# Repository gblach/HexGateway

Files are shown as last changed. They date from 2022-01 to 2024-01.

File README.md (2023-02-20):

# HexGateway
An internet gateway for Bluetooth LE, OpenThread and/or Zigbee devices.

It employs three chips:
- nrf52840 - has support for Bluetooth LE, OpenThread and Zigbee networks.
- esp32-c3 - has support for WiFi at 2.4GHz.
- enc28j60 - has support for Ethernet network.

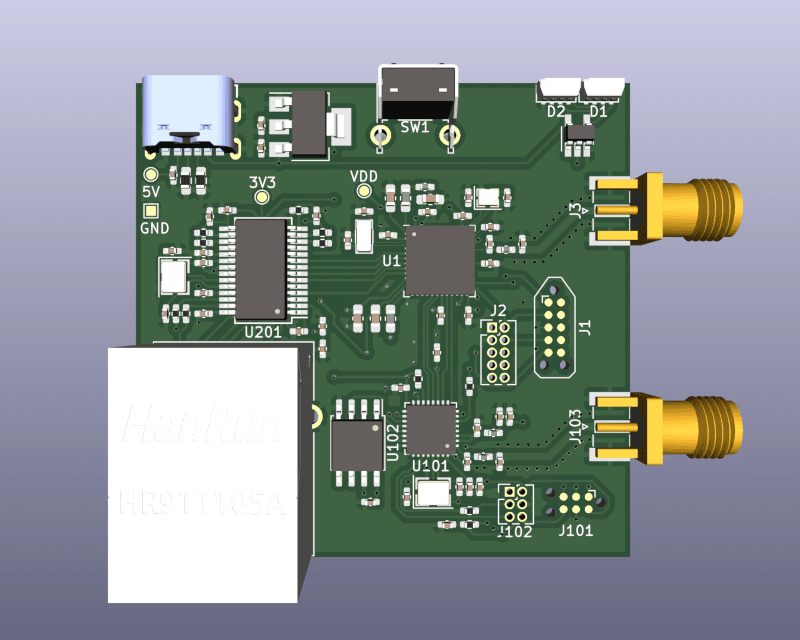
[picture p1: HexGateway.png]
HexGateway render


## Hardware
To build your own board you need this [gerber file](HexGateway.zip) and [bill of materials](HexGateway.csv).

Note that U102 is required only if your are using esp32-c3 (U101) without built-in flash memory.

## Programmers
nrf52840 (U1) can be programmed using the standalone [Segger J-Link](https://www.segger.com/products/debug-probes/j-link/) or the on-board Segger J-Link (this can be found for e.g. on [nrf52840dk](https://www.nordicsemi.com/Products/Development-hardware/nRF52840-DK) board). This programmer must be connected to J1 (TagConnect) or J2 (IDC 10) connector.

esp32-c3 (U101) can be programmed using [ESP-Prog](https://docs.espressif.com/projects/espressif-esp-iot-solution/en/latest/hw-reference/ESP-Prog_guide.html). This programmer must be connected to J101 (TagConnect) or J102 (IDC 6) connector.

enc28j60 (U201) does not need to be programmed.

## Software
For the nrf52840 chip you have to write your own software that will meet your requirements. The best way is to use [Zephyr RTOS](https://www.zephyrproject.org/). The board definition for Zephyr can be found in [boards/arm/hexgw1](boards/arm/hexgw1) directory.

esp32-c3 can be controlled with AT commands. To do this, you need to upload [ESP-AT](https://github.com/espressif/esp-at) firmware.

## Sponsorship
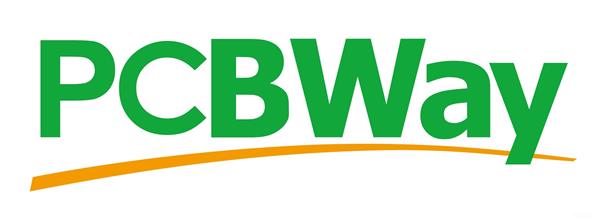
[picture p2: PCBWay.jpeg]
PCBWay (https://pcbway.com/g/7D2Z6d)


The production of these gateways was sponsored by [PCBWay](https://pcbway.com/g/7D2Z6d), they manufacture prototype PCBs and assemble components on the boards. I got 5 almost complete devices from this company for testing and evaluation, I had to solder only connectors for antennas and RJ45 ports by myself.

The visual impression of the boards is very good. All the contacts are gold plated, the silkscreen is readable, the whole board is thoroughly covered with soldiermask and all the components are soldered with a small amount of tin, so I was not worried about a potential short circuit anywhere.

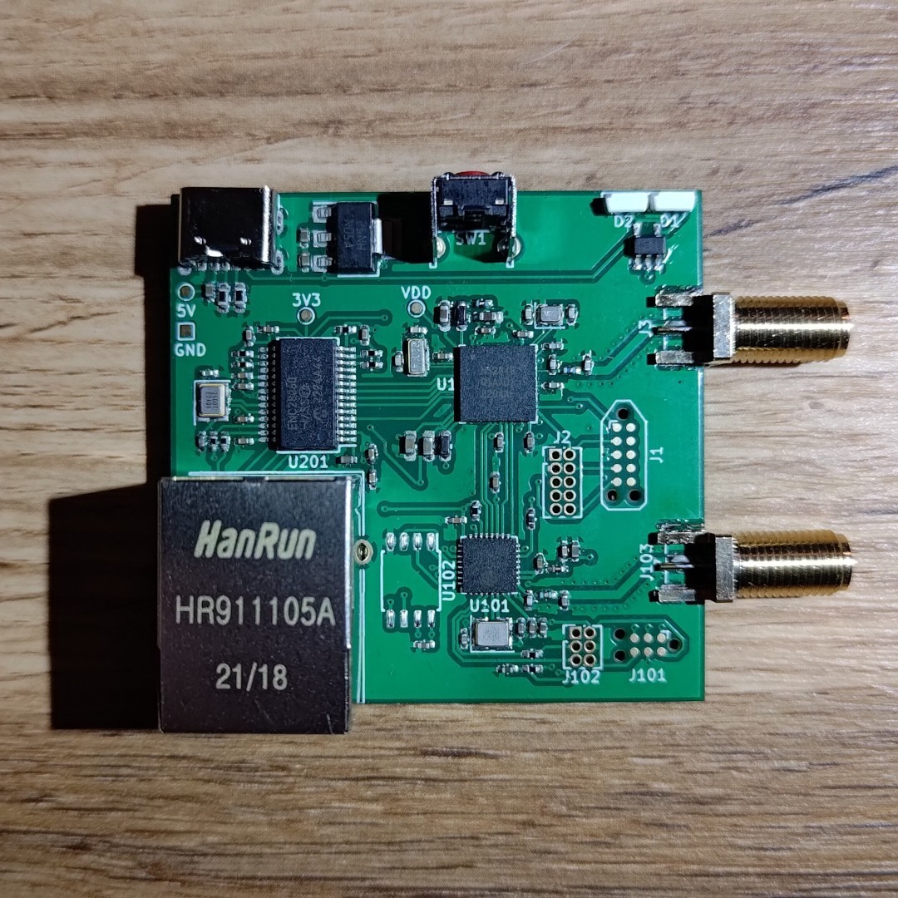
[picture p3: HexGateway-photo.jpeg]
HexGateway photo


So it remained to upload test programs to check if everything works properly. First I uploaded ESP-AT to the ESP32-C3 chips, and that passed without any problem. Next, I uploaded four programs one at a time to the nRF52840 chips. The first to check if bluetooth works, the second to check WiFi operation, the third to check Ethernet and the fourth to check LEDs. In the case of 4/5 boards, everything works as expected, so they are fully functional devices. However, for the fifth one, the programmer gave me a message that it does not detect the voltage of the processor. With a multimeter I checked the voltage on the VDD pin and there was indeed 0V there. This means that this chip is defective or more likely not all pins are soldered correctly. I am not surprised by this situation, because the nrf52840 chip has very small and densely spaced pins, so if something was to be soldered wrong, it would be with this chip.

My final rating for the quality of devices produced by [PCBWay](https://pcbway.com/g/7D2Z6d) is 4/5 stars, and this is higher than the two competing companies I have worked with. So I will probably change the company where I will produce the PCBs in the future.

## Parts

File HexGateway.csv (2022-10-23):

Ref | Qnty | Value | Cmp name | Footprint | Description | Vendor
C1, C2, C17, C18, | 4 | 12pF, NP0, 2% | C | Capacitor_SMD:C_0402_1005Metric_Pad0.74x0.62mm_HandSolder | Unpolarized capacitor
C3, | 1 | 0.8pF, NP0, 10% | C | Capacitor_SMD:C_0402_1005Metric_Pad0.74x0.62mm_HandSolder | Unpolarized capacitor
C4, | 1 | 0.5pF, NP0, 10% | C | Capacitor_SMD:C_0402_1005Metric_Pad0.74x0.62mm_HandSolder | Unpolarized capacitor
C5, C7, C8, C12, C106, C107, C110, C112, C201, C202, C203, C204, C205, C208, C209, | 15 | 100nF, X7R, 10% | C | Capacitor_SMD:C_0402_1005Metric_Pad0.74x0.62mm_HandSolder | Unpolarized capacitor
C6, C19, | 2 | 4.7uF, X7R, 10% | C | Capacitor_SMD:C_0603_1608Metric_Pad1.08x0.95mm_HandSolder | Unpolarized capacitor
C9, | 1 | 820pF, NP0, 5% | C | Capacitor_SMD:C_0402_1005Metric_Pad0.74x0.62mm_HandSolder | Unpolarized capacitor
C11, | 1 | 100pF, NP0, 5% | C | Capacitor_SMD:C_0402_1005Metric_Pad0.74x0.62mm_HandSolder | Unpolarized capacitor
C14, C15, | 2 | 1.0uF, X7R, 10% | C | Capacitor_SMD:C_0603_1608Metric_Pad1.08x0.95mm_HandSolder | Unpolarized capacitor
C16, | 1 | 47nF, X7R, 10% | C | Capacitor_SMD:C_0402_1005Metric_Pad0.74x0.62mm_HandSolder | Unpolarized capacitor
C50, C51, C52, C105, C211, | 5 | 10uF, 20% | C | Capacitor_SMD:C_0402_1005Metric_Pad0.74x0.62mm_HandSolder | Unpolarized capacitor
C101, C102, C220, C221, | 4 | 20pF | C | Capacitor_SMD:C_0402_1005Metric_Pad0.74x0.62mm_HandSolder | Unpolarized capacitor
C103, C111, C150, | 3 | 1uF, 20% | C | Capacitor_SMD:C_0402_1005Metric_Pad0.74x0.62mm_HandSolder | Unpolarized capacitor
C104, C206, C207, | 3 | 10nF, 10% | C | Capacitor_SMD:C_0402_1005Metric_Pad0.74x0.62mm_HandSolder | Unpolarized capacitor
C108, | 1 | 2.0pF | C | Capacitor_SMD:C_0402_1005Metric_Pad0.74x0.62mm_HandSolder | Unpolarized capacitor
C109, | 1 | 1.5pF | C | Capacitor_SMD:C_0402_1005Metric_Pad0.74x0.62mm_HandSolder | Unpolarized capacitor
D1, D2, | 2 | WS2812B | WS2812B | WS2812B_4020:WS2812B_4020 | RGB LED with integrated controller
J1, | 1 | Conn_02x05_Counter_Clockwise | Conn_02x05_Counter_Clockwise | Connector:Tag-Connect_TC2050-IDC-NL_2x05_P1.27mm_Vertical_with_bottom_clip | Generic connector, double row, 02x05, counter clockwise pin numbering scheme (similar to DIP packge numbering), script generated (kicad-library-utils/schlib/autogen/connector/)
J2, | 1 | Conn_02x05_Odd_Even | Conn_02x05_Odd_Even | Connector_PinHeader_1.27mm:PinHeader_2x05_P1.27mm_Vertical | Generic connector, double row, 02x05, odd/even pin numbering scheme (row 1 odd numbers, row 2 even numbers), script generated (kicad-library-utils/schlib/autogen/connector/)
J3, J103, | 2 | Conn_Coaxial | Conn_Coaxial_Power | SMA_EdgeMount:SMA_EdgeMount | coaxial connector (BNC, SMA, SMB, SMC, Cinch/RCA, LEMO, ...)
J4, | 1 | USB4125-GF-A_REVA | USB4125-GF-A_REVA | USB-C:GCT_USB4125-GF-A_REVA
J101, | 1 | Conn_02x03_Odd_Even | Conn_02x03_Odd_Even | Connector:Tag-Connect_TC2030-IDC-NL_2x03_P1.27mm_Vertical | Generic connector, double row, 02x03, odd/even pin numbering scheme (row 1 odd numbers, row 2 even numbers), script generated (kicad-library-utils/schlib/autogen/connector/)
J102, | 1 | Conn_02x03_Odd_Even | Conn_02x03_Odd_Even | Connector_PinHeader_1.27mm:PinHeader_2x03_P1.27mm_Vertical | Generic connector, double row, 02x03, odd/even pin numbering scheme (row 1 odd numbers, row 2 even numbers), script generated (kicad-library-utils/schlib/autogen/connector/)
J201, | 1 | RJ45_Hanrun_HR911105A | RJ45_Hanrun_HR911105A | RJ45_Hanrun_HR911105A:RJ45_Hanrun_HR911105A
L1, | 1 | 4.7nH, 5% | L | Inductor_SMD:L_0402_1005Metric_Pad0.77x0.64mm_HandSolder | Inductor
L2, L4, | 2 | 10uH, 80mA, 20% | L | Inductor_SMD:L_0603_1608Metric_Pad1.05x0.95mm_HandSolder | Inductor
L3, | 1 | 15nH, 10% | L | Inductor_SMD:L_0402_1005Metric_Pad0.77x0.64mm_HandSolder | Inductor
L101, | 1 | 2.0nH, (0.1nH), 450mA | L | Inductor_SMD:L_0402_1005Metric_Pad0.77x0.64mm_HandSolder | Inductor
L102, | 1 | 3.9nH | L | Inductor_SMD:L_0402_1005Metric_Pad0.77x0.64mm_HandSolder | Inductor
R1, R2, | 2 | 5.1k, 10% | R | Resistor_SMD:R_0603_1608Metric_Pad0.98x0.95mm_HandSolder | Resistor
R102, | 1 | 499R, 1%, 1/20W | R | Resistor_SMD:R_0402_1005Metric_Pad0.72x0.64mm_HandSolder | Resistor
R108, R120, R150, | 3 | 10k, 1% | R | Resistor_SMD:R_0402_1005Metric_Pad0.72x0.64mm_HandSolder | Resistor
R201, | 1 | 2.32k, 1% | R | Resistor_SMD:R_0402_1005Metric_Pad0.72x0.64mm_HandSolder | Resistor
R202, R203, R204, R205, | 4 | 50R, 1% | R | Resistor_SMD:R_0402_1005Metric_Pad0.72x0.64mm_HandSolder | Resistor
R206, R207, | 2 | 330R | R | Resistor_SMD:R_0402_1005Metric_Pad0.72x0.64mm_HandSolder | Resistor
SW1, | 1 | SW_Push | SW_Push | Button_Switch_THT:SW_Tactile_SPST_Angled_PTS645Vx31-2LFS | Push button switch, generic, two pins
TP1, | 1 | TestPoint_Small | TestPoint_Small | TestPoint:TestPoint_Pad_1.0x1.0mm | test point
TP2, TP3, TP4, | 3 | TestPoint_Small | TestPoint_Small | TestPoint:TestPoint_Pad_D1.0mm | test point
U1, | 1 | nRF52840 | nRF52840 | Package_DFN_QFN:Nordic_AQFN-73-1EP_7x7mm_P0.5mm | Multiprotocol BLE/ANT/2.4 GHz/802.15.4 Cortex-M4F SoC, AQFN-73
U2, | 1 | LM1117-3.3 | LM1117-3.3 | Package_TO_SOT_SMD:SOT-223-3_TabPin2 | 800mA Low-Dropout Linear Regulator, 3.3V fixed output, TO-220/TO-252/TO-263/SOT-223
U5, | 1 | SN74LV1T34DBV | SN74LV1T34DBV | Package_TO_SOT_SMD:SOT-23-5_HandSoldering | Single Power Supply, Single Buffer GATE, CMOS Logic, Level Shifter, SOT-23-5
U101, | 1 | esp32-c3 | esp32-c3 | Package_DFN_QFN:QFN-32-1EP_5x5mm_P0.5mm_EP3.7x3.7mm | https://www.espressif.com/en/products/socs/esp32-c3
U102, | 1 | MX25R3235FM2xx1 | MX25R3235FM2xx1 | Package_SO:SOP-8_5.28x5.23mm_P1.27mm | 32-Mbit, Wide Range Voltage SPI Serial Flash Memory, SOP-8
U201, | 1 | ENC28J60x-SS | ENC28J60x-SS | Package_SO:SSOP-28_5.3x10.2mm_P0.65mm | ENC28J60 Single Chip Ethernet Interface, SSOP-28
X1, | 1 | 32MHz, 8pF, 40ppm | Crystal_GND24 | Crystals:Crystal_SMD_2016-4Pin_2.0x1.6mm | Four pin crystal, GND on pins 2 and 4
X2, | 1 | 32.768kHz, 9pF, 50ppm | Crystal | Crystals:Crystal_SMD_3215-2Pin_3.2x1.5mm | Two pin crystal
X201, | 1 | 25MHz, 15/16pF | Crystal_GND24 | Crystal:Crystal_SMD_3225-4Pin_3.2x2.5mm | Four pin crystal, GND on pins 2 and 4
Y101, | 1 | 40MHz, 15pF, 10ppm | Crystal_GND24 | Crystal:Crystal_SMD_3225-4Pin_3.2x2.5mm | Four pin crystal, GND on pins 2 and 4

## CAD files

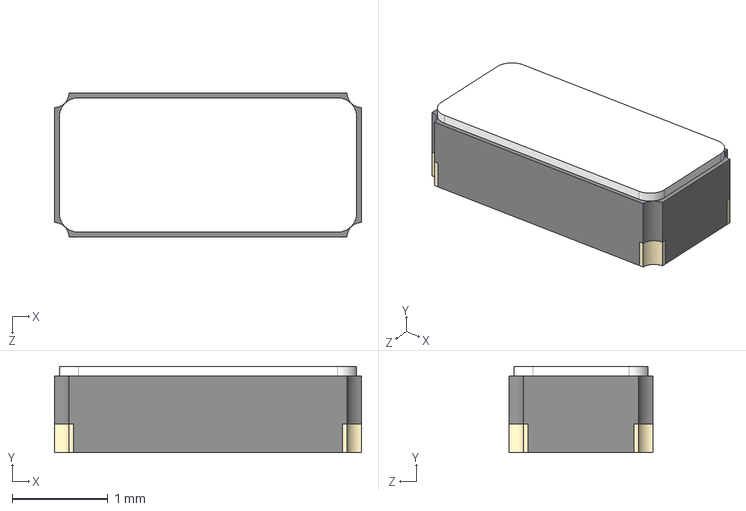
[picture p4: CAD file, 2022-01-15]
Crystals.models/Crystal_SMD_3215.step
3.20 x 0.9 x 1.50 mm

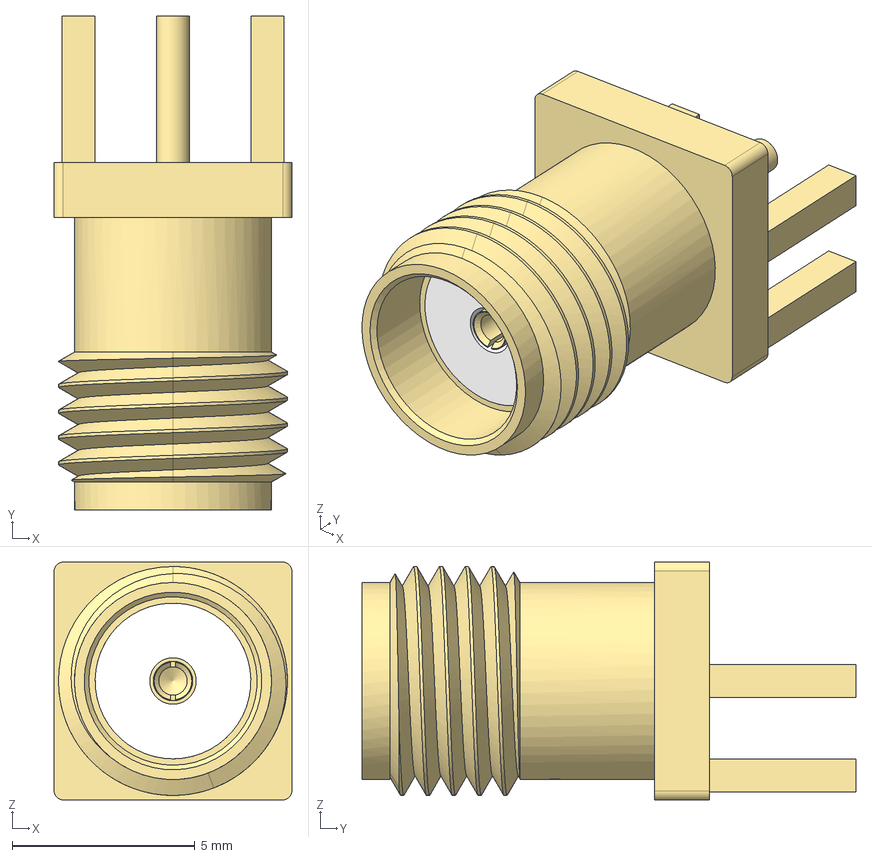
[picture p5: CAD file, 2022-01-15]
SMA_EdgeMount.models/SMA_EdgeMount.step
6.50 x 13.5 x 6.50 mm
Dielectric
Pin

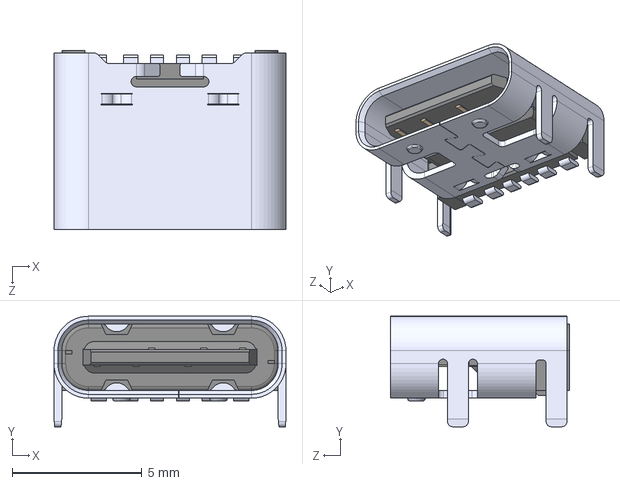
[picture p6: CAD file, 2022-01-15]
USB4125-GF-A_REVA.models/GCT_USB4125-GF-A_REVA.step
8.94 x 4.26 x 6.90 mm

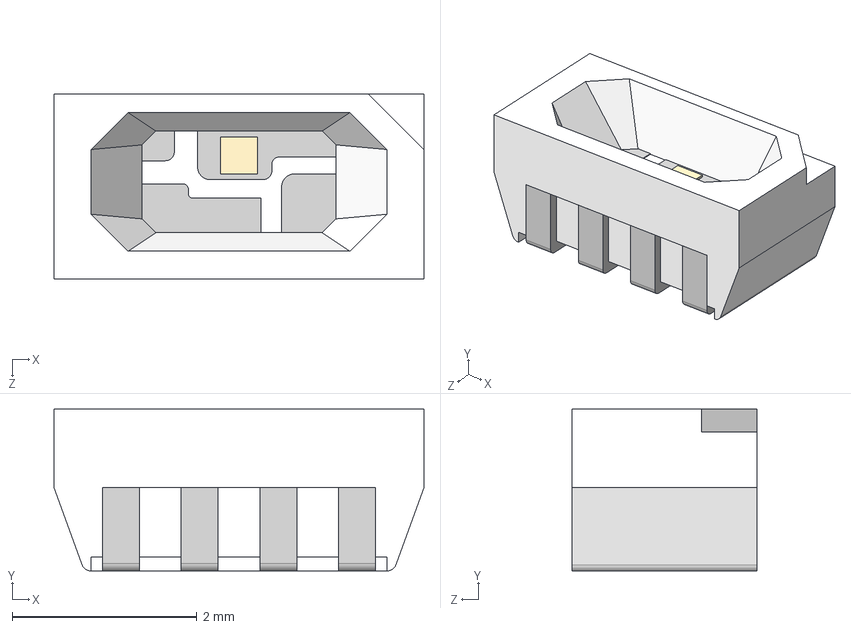
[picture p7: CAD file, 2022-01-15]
WS2812B_4020.models/WS2812B_4020.step
4.00 x 1.75 x 2.00 mm

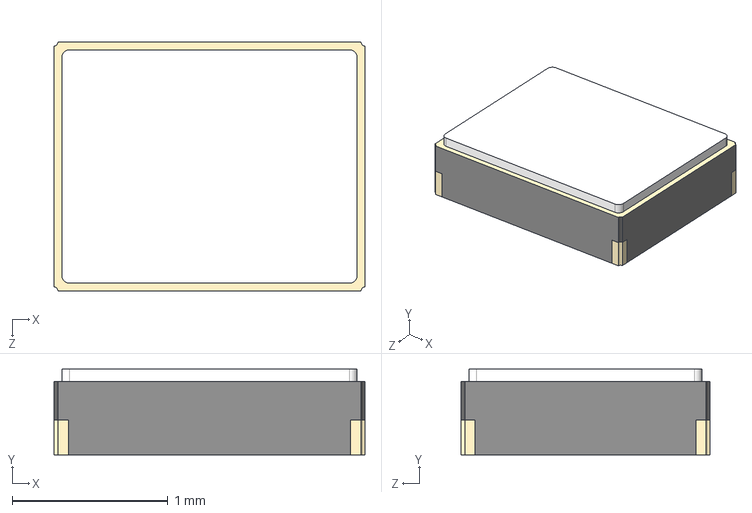
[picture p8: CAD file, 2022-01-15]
Crystals.models/Crystal_SMD_2016.step
2.00 x 0.55 x 1.60 mm

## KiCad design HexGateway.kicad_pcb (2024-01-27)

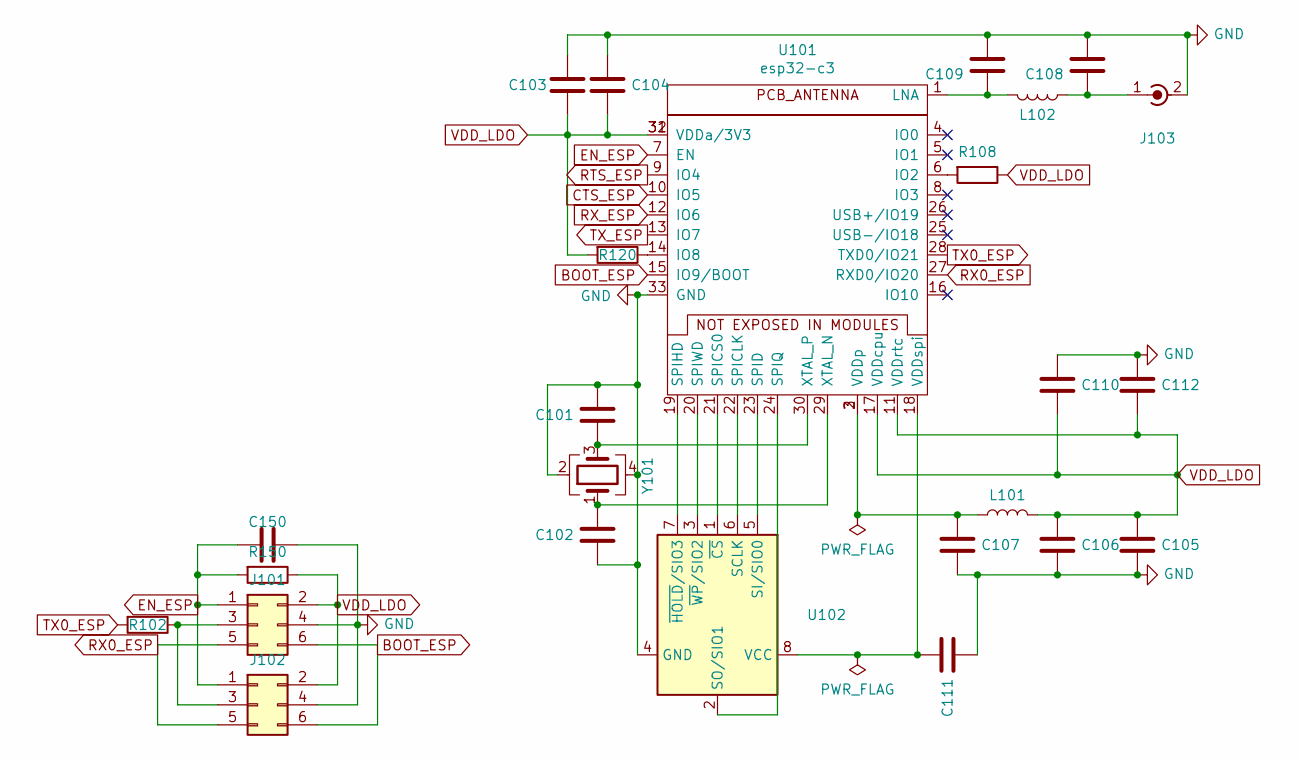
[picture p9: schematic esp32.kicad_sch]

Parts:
C101, C102: 20pF; C_0402_1005Metric_Pad0.74x0.62mm_HandSolder; LCSC C1554
C103, C150: 1uF, 20%; C_0402_1005Metric_Pad0.74x0.62mm_HandSolder; LCSC C52923
C104: 10nF, 10%; C_0402_1005Metric_Pad0.74x0.62mm_HandSolder; LCSC C15195
C105: 10uF, 20%; C_0402_1005Metric_Pad0.74x0.62mm_HandSolder; LCSC C15525
C106, C107, C110, C112: 100nF, X7R, 10%; C_0402_1005Metric_Pad0.74x0.62mm_HandSolder; LCSC C1525
C108: 2.0pF; C_0402_1005Metric_Pad0.74x0.62mm_HandSolder; LCSC C1558
C109: 1.5pF; C_0402_1005Metric_Pad0.74x0.62mm_HandSolder; LCSC C23967
C111: 1uF, 20%; C_0402_1005Metric_Pad0.74x0.62mm_HandSolder; LCSC C29266
J101: Conn_02x03_Odd_Even; Tag-Connect_TC2030-IDC-NL_2x03_P1.27mm_Vertical
J102: Conn_02x03_Odd_Even; PinHeader_2x03_P1.27mm_Vertical
J103: Conn_Coaxial; SMA_EdgeMount
L101: 2.0nH, (0.1nH), 450mA; L_0402_1005Metric_Pad0.77x0.64mm_HandSolder; LCSC C87176
L102: 3.9nH; L_0402_1005Metric_Pad0.77x0.64mm_HandSolder; LCSC C14033
R102: 499R, 1%, 1/20W; R_0402_1005Metric_Pad0.72x0.64mm_HandSolder; LCSC C57982
R108, R120, R150: 10k, 1%; R_0402_1005Metric_Pad0.72x0.64mm_HandSolder; LCSC C25744
U101: esp32-c3; QFN-32-1EP_5x5mm_P0.5mm_EP3.7x3.7mm; LCSC C2838500
U102: MX25R3235FM2xx1; SOP-8_5.28x5.23mm_P1.27mm; LCSC C18192
Y101: 40MHz, 15pF, 10ppm; Crystal_SMD_3225-4Pin_3.2x2.5mm; LCSC C90935

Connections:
BOOT_ESP: J101.6, J102.6, U101.15 (IO9/BOOT)
CTS_ESP: U101.10 (IO5); also elsewhere on the board
EN_ESP: C150.1, J101.1, J102.1, R150.2, U101.7 (EN)
GND: C101.2, C102.2, C103.1, C104.1, C105.2, C106.2, C107.2, C108.2, C109.2, C110.1, C111.1, C112.1, C150.2, J101.4, J102.4, J103.2 (Ext), U101.33 (GND), U102.4 (GND), Y101.2, Y101.4; also elsewhere on the board
unnamed: C101.1, U101.30 (XTAL_P), Y101.3
unnamed: C102.1, U101.29 (XTAL_N), Y101.1
unnamed: C107.1, L101.1, U101.2 (VDDp), U101.3 (VDDp)
unnamed: C108.1, J103.1 (In), L102.1
unnamed: C109.1, L102.2, U101.1 (LNA)
unnamed: C111.2, U101.18 (VDDspi), U102.8 (VCC)
unnamed: J101.3, J102.3, R102.1
unnamed: R108.2, U101.6 (IO2)
unnamed: R120.1, U101.14 (IO8)
unnamed: U101.19 (SPIHD), U102.7 (~HOLD/SIO3)
unnamed: U101.20 (SPIWD), U102.3 (~WP/SIO2)
unnamed: U101.21 (SPICS0), U102.1 (~CS)
unnamed: U101.22 (SPICLK), U102.6 (SCLK)
unnamed: U101.23 (SPID), U102.5 (SI/SIO0)
unnamed: U101.24 (SPIQ), U102.2 (SO/SIO1)
RTS_ESP: U101.9 (IO4); also elsewhere on the board
RX0_ESP: J101.5, J102.5, U101.27 (RXD0/IO20)
RX_ESP: U101.12 (IO6); also elsewhere on the board
TX0_ESP: R102.2, U101.28 (TXD0/IO21)
TX_ESP: U101.13 (IO7); also elsewhere on the board
VDD_LDO: C103.2, C104.2, C105.1, C106.1, C110.2, C112.2, J101.2, J102.2, L101.2, R108.1, R120.2, R150.1, U101.11 (VDDrtc), U101.17 (VDDcpu), U101.31 (VDDa/3V3), U101.32 (VDDa/3V3); also elsewhere on the board

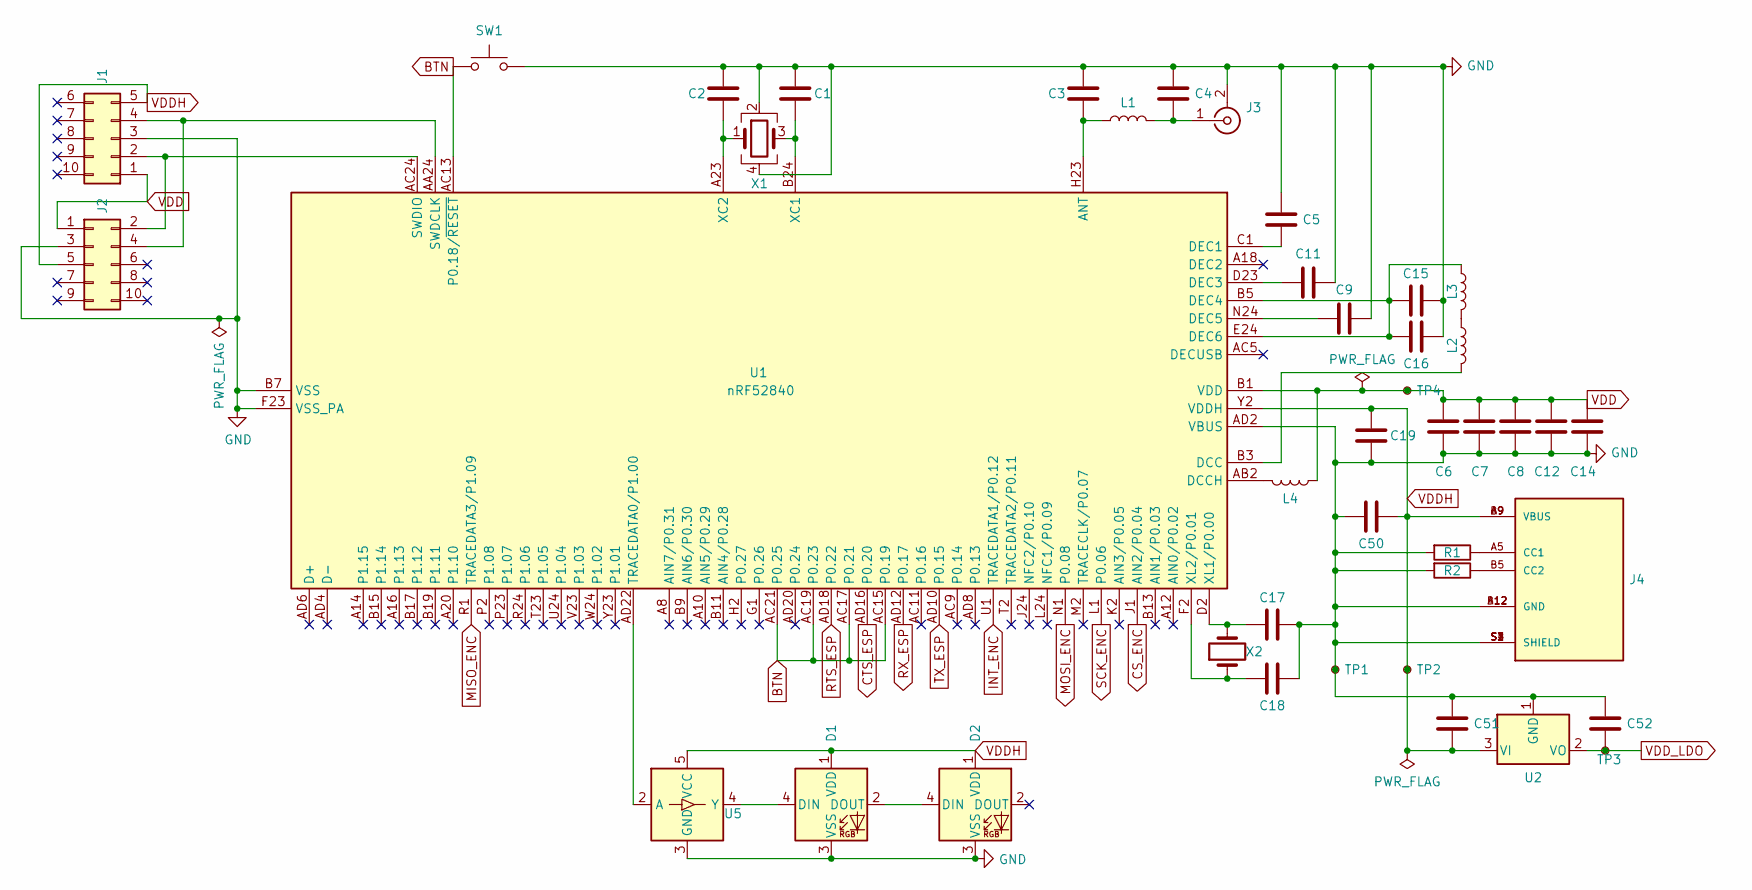
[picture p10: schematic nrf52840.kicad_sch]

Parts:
C1, C2, C17, C18: 12pF, NP0, 2%; C_0402_1005Metric_Pad0.74x0.62mm_HandSolder; LCSC C1547
C3: 0.8pF, NP0, 10%; C_0402_1005Metric_Pad0.74x0.62mm_HandSolder; LCSC C326068
C4: 0.5pF, NP0, 10%; C_0402_1005Metric_Pad0.74x0.62mm_HandSolder; LCSC C86284
C5, C7, C8, C12: 100nF, X7R, 10%; C_0402_1005Metric_Pad0.74x0.62mm_HandSolder; LCSC C1525
C6, C19: 4.7uF, X7R, 10%; C_0603_1608Metric_Pad1.08x0.95mm_HandSolder; LCSC C19666
C9: 820pF, NP0, 5%; C_0402_1005Metric_Pad0.74x0.62mm_HandSolder; LCSC C307452
C11: 100pF, NP0, 5%; C_0402_1005Metric_Pad0.74x0.62mm_HandSolder; LCSC C1546
C14, C15: 1.0uF, X7R, 10%; C_0603_1608Metric_Pad1.08x0.95mm_HandSolder; LCSC C15849
C16: 47nF, X7R, 10%; C_0402_1005Metric_Pad0.74x0.62mm_HandSolder; LCSC C26403
C50, C51, C52: 10uF, 20%; C_0402_1005Metric_Pad0.74x0.62mm_HandSolder; LCSC C15525
D1, D2: WS2812B; WS2812B_4020; LCSC C965557
J1: Conn_02x05_Counter_Clockwise; Tag-Connect_TC2050-IDC-NL_2x05_P1.27mm_Vertical_with_bottom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
J2: Conn_02x05_Odd_Even; PinHeader_2x05_P1.27mm_Vertical
J3: Conn_Coaxial; SMA_EdgeMount
J4: USB4125-GF-A_REVA; GCT_USB4125-GF-A_REVA; PARTREV Rev A; LCSC C283540
L1: 4.7nH, 5%; L_0402_1005Metric_Pad0.77x0.64mm_HandSolder; LCSC C13595
L2, L4: 10uH, 80mA, 20%; L_0603_1608Metric_Pad1.05x0.95mm_HandSolder; LCSC C87216
L3: 15nH, 10%; L_0402_1005Metric_Pad0.77x0.64mm_HandSolder; LCSC C27143
R1, R2: 5.1k, 10%; R_0603_1608Metric_Pad0.98x0.95mm_HandSolder; LCSC C23186
SW1: SW_Push; SW_Tactile_SPST_Angled_PTS645Vx31-2LFS
TP1: TestPoint_Small; TestPoint_Pad_1.0x1.0mm
TP2, TP3, TP4: TestPoint_Small; TestPoint_Pad_D1.0mm
U1: nRF52840; Nordic_AQFN-73-1EP_7x7mm_P0.5mm; LCSC C190794
U2: LM1117-3.3; SOT-223-3_TabPin2; LCSC C6186
U5: SN74LV1T34DBV; SOT-23-5_HandSoldering; LCSC C100024
X1: 32MHz, 8pF, 40ppm; Crystal_SMD_2016-4Pin_2.0x1.6mm; LCSC C187794
X2: 32.768kHz, 9pF, 50ppm; Crystal_SMD_3215-2Pin_3.2x1.5mm; LCSC C32346

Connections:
BTN: SW1.2, U1.AC13 (P0.18/~RESET), U1.AC15 (P0.19), U1.AC17 (P0.21), U1.AC19 (P0.23), U1.AC21 (P0.25)
CS_ENC: U1.J1 (AIN2/P0.04); also elsewhere on the board
CTS_ESP: U1.AD16 (P0.20); also elsewhere on the board
GND: C1.1, C2.2, C3.1, C4.1, C5.1, C6.2, C7.2, C8.2, C9.1, C11.1, C12.2, C14.2, C15.1, C16.2, C17.2, C18.1, C19.2, C50.1, C51.1, C52.1, D1.3 (VSS), D2.3 (VSS), J1.3, J2.3, J3.2 (Ext), J4.A12 (GND), J4.B12 (GND), J4.S1 (SHIELD), J4.S2 (SHIELD), J4.S3 (SHIELD), J4.S4 (SHIELD), R1.2, R2.2, SW1.1, TP1.1, U1.AD2 (VBUS), U1.B7 (VSS), U1.EP (VSS), U1.F23 (VSS_PA), U2.1 (GND), U5.3 (GND), X1.2, X1.4; also elsewhere on the board
INT_ENC: U1.U1 (TRACEDATA1/P0.12); also elsewhere on the board
MISO_ENC: U1.R1 (TRACEDATA3/P1.09); also elsewhere on the board
MOSI_ENC: U1.N1 (P0.08); also elsewhere on the board
unnamed: C1.2, U1.B24 (XC1), X1.3
unnamed: C2.1, U1.A23 (XC2), X1.1
unnamed: C3.2, L1.1, U1.H23 (ANT)
unnamed: C4.2, J3.1 (In), L1.2
unnamed: C5.2, U1.C1 (DEC1)
unnamed: C9.2, U1.N24 (DEC5)
unnamed: C11.2, U1.D23 (DEC3)
unnamed: C15.2, C16.1, L3.1, U1.B5 (DEC4), U1.E24 (DEC6)
unnamed: C17.1, U1.D2 (XL1/P0.00), X2.2
unnamed: C18.2, U1.F2 (XL2/P0.01), X2.1
unnamed: D1.2 (DOUT), D2.4 (DIN)
unnamed: D1.4 (DIN), U5.4 (Y)
unnamed: J1.2, J2.2, U1.AC24 (SWDIO)
unnamed: J1.4, J2.4, U1.AA24 (SWDCLK)
unnamed: J4.A5 (CC1), R1.1
unnamed: J4.B5 (CC2), R2.1
unnamed: L2.1, L3.2
unnamed: L2.2, U1.B3 (DCC)
unnamed: L4.2, U1.AB2 (DCCH)
unnamed: U1.AD22 (TRACEDATA0/P1.00), U5.2 (A)
RTS_ESP: U1.AD18 (P0.22); also elsewhere on the board
RX_ESP: U1.AD12 (P0.17); also elsewhere on the board
SCK_ENC: U1.L1 (P0.06); also elsewhere on the board
TX_ESP: U1.AD10 (P0.15); also elsewhere on the board
VDD: C6.1, C7.1, C8.1, C12.1, C14.1, J1.1, J2.1, L4.1, TP4.1, U1.A22 (VDD), U1.AD14 (VDD), U1.AD23 (VDD), U1.B1 (VDD), U1.W1 (VDD); also elsewhere on the board
VDDH: C19.1, C50.2, C51.2, D1.1 (VDD), D2.1 (VDD), J1.5, J2.5, J4.A9 (VBUS), J4.B9 (VBUS), TP2.1, U1.Y2 (VDDH), U2.3 (VI), U5.5 (VCC); also elsewhere on the board
VDD_LDO: C52.2, TP3.1, U2.2 (VO); also elsewhere on the board

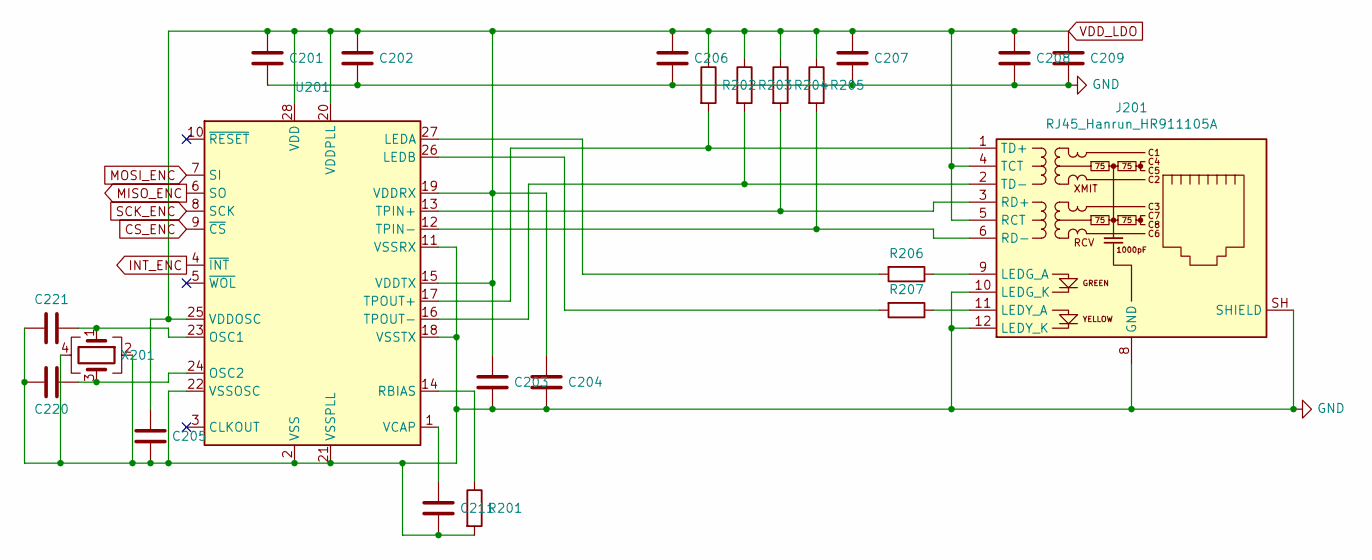
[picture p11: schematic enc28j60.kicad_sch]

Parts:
C201, C202, C203, C204, C205, C208, C209: 100nF, X7R, 10%; C_0402_1005Metric_Pad0.74x0.62mm_HandSolder; LCSC C1525
C206, C207: 10nF, 10%; C_0402_1005Metric_Pad0.74x0.62mm_HandSolder; LCSC C15195
C211: 10uF, 20%; C_0402_1005Metric_Pad0.74x0.62mm_HandSolder; LCSC C15525
C220, C221: 20pF; C_0402_1005Metric_Pad0.74x0.62mm_HandSolder; LCSC C1554
J201: RJ45_Hanrun_HR911105A
R201: 2.32k, 1%; R_0402_1005Metric_Pad0.72x0.64mm_HandSolder; LCSC C82297
R202, R203, R204, R205: 50R, 1%; R_0402_1005Metric_Pad0.72x0.64mm_HandSolder; LCSC C25120
R206, R207: 330R; R_0402_1005Metric_Pad0.72x0.64mm_HandSolder; LCSC C25104
U201: ENC28J60x-SS; SSOP-28_5.3x10.2mm_P0.65mm; LCSC C411626
X201: 25MHz, 15/16pF; Crystal_SMD_3225-4Pin_3.2x2.5mm; LCSC C9006

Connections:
CS_ENC: U201.9 (~CS); also elsewhere on the board
GND: C201.2, C202.2, C203.2, C204.2, C205.2, C206.2, C207.2, C208.2, C209.2, C211.2, C220.2, C221.2, J201.8 (GND), J201.10 (LEDG_K), J201.12 (LEDY_K), J201.SH (SHIELD), R201.2, U201.2 (VSS), U201.11 (VSSRX), U201.18 (VSSTX), U201.21 (VSSPLL), U201.22 (VSSOSC), X201.2, X201.4; also elsewhere on the board
INT_ENC: U201.4 (~INT); also elsewhere on the board
MISO_ENC: U201.6 (SO); also elsewhere on the board
MOSI_ENC: U201.7 (SI); also elsewhere on the board
unnamed: C211.1, U201.1 (VCAP)
unnamed: C220.1, U201.24 (OSC2), X201.3
unnamed: C221.1, U201.23 (OSC1), X201.1
unnamed: J201.1 (TD+), R202.2, U201.17 (TPOUT+)
unnamed: J201.2 (TD-), R203.2, U201.16 (TPOUT-)
unnamed: J201.3 (RD+), R204.2, U201.13 (TPIN+)
unnamed: J201.6 (RD-), R205.2, U201.12 (TPIN-)
unnamed: J201.9 (LEDG_A), R206.1
unnamed: J201.11 (LEDY_A), R207.1
unnamed: R201.1, U201.14 (RBIAS)
unnamed: R206.2, U201.27 (LEDA)
unnamed: R207.2, U201.26 (LEDB)
SCK_ENC: U201.8 (SCK); also elsewhere on the board
VDD_LDO: C201.1, C202.1, C203.1, C204.1, C205.1, C206.1, C207.1, C208.1, C209.1, J201.4 (TCT), J201.5 (RCT), R202.1, R203.1, R204.1, R205.1, U201.15 (VDDTX), U201.19 (VDDRX), U201.20 (VDDPLL), U201.25 (VDDOSC), U201.28 (VDD); also elsewhere on the board

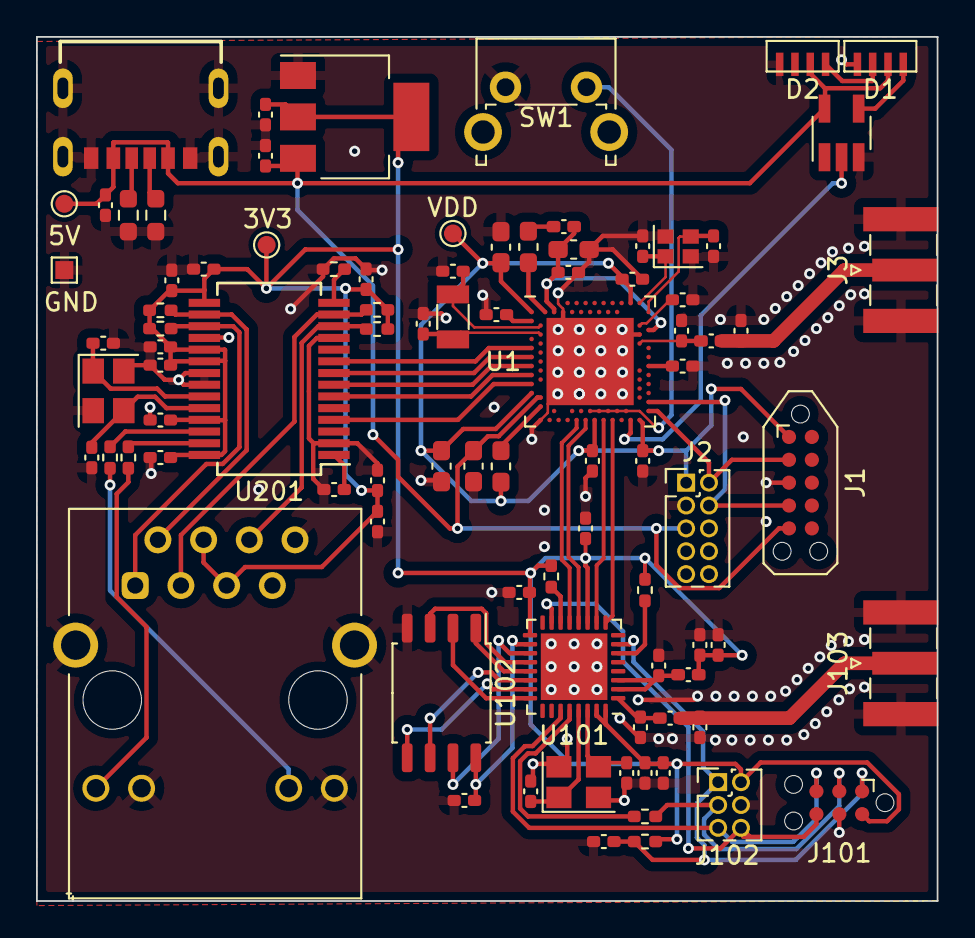
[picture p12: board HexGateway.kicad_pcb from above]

Board: 2 copper layers, 50.0 x 48.0 mm, 89 parts (0 on the bottom side), 65 nets.

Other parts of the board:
3V3, 5V: TestPoint_Small; TestPoint_Pad_D1.0mm
GND: TestPoint_Small; TestPoint_Pad_1.0x1.0mm
VDD: TestPoint_Small; TestPoint_Pad_D1.0mm

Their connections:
GND: GND.1; also elsewhere on the board
VDD: VDD.1; also elsewhere on the board
VDDH: 5V.1; also elsewhere on the board
VDD_LDO: 3V3.1; also elsewhere on the board

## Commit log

2022-01-15 Initial import
    [Crystal_SMD_2016.step, Crystal_SMD_3215.step, GCT_USB4125-GF-A_REVA.step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]
2022-10-23 Remove header
    [HexGateway.csv]
2023-01-28 Add support for pyOCD, OpenOCD and Black Magic Probe
2024-01-27 Update project to KiCad 7
    [HexGateway.kicad_pcb, HexGateway.kicad_sch, enc28j60.kicad_sch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]
2024-01-27 Update board files to zephyr 3.5
